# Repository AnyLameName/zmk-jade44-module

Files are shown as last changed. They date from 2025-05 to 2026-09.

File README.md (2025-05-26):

# Jade44 - A ZMK Keyboard Module

The Jade44 keyboard is a bespoke keyboard, designed for a userbase of one. 
This repository contains a module for the [ZMK Firmware](https://zmk.dev/) Project that will enable you to build
a firmware for the Jade44.

It also defines a GitHub Actions Workflow that will automatically build the firmware when a change is pushed.

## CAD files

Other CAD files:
kicad/models/EC12E2440301/ec12e2440301_3D.dxf

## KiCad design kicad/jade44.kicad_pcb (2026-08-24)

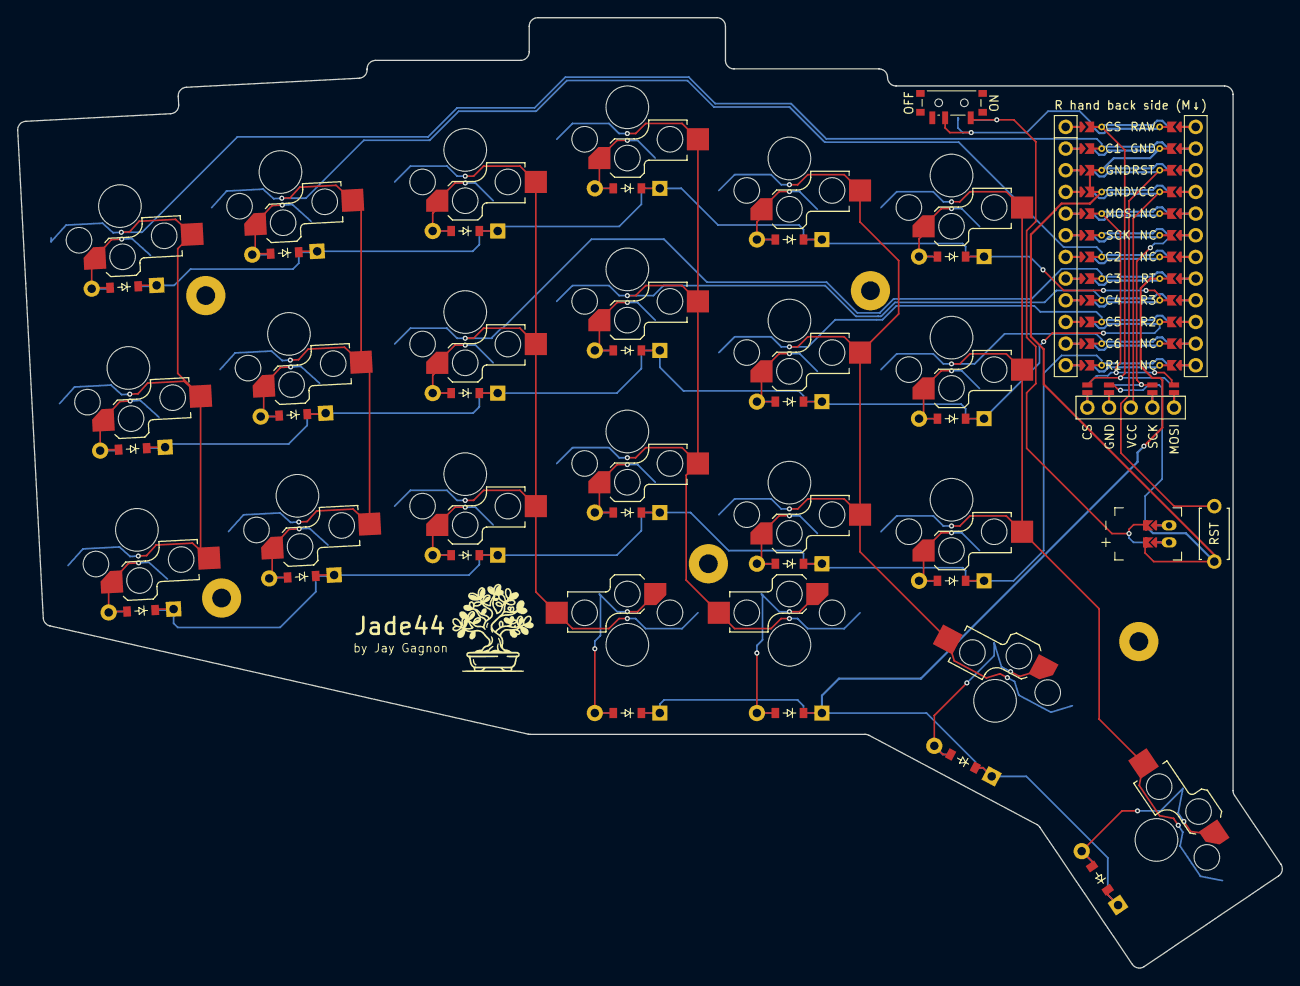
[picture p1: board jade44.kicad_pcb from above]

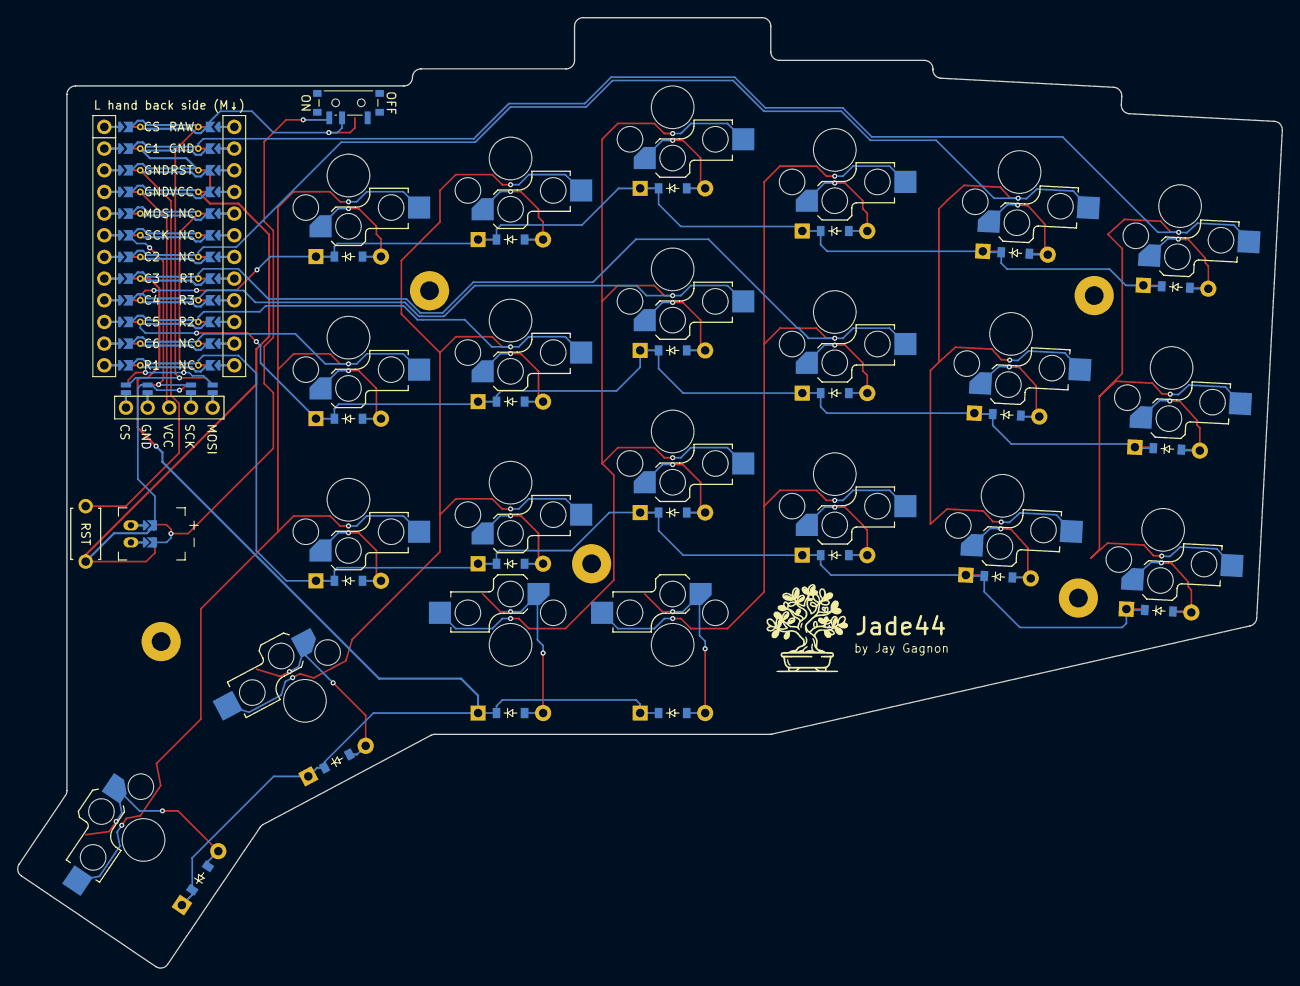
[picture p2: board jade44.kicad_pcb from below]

Board: 2 copper layers, 148.2 x 111.4 mm, 54 parts (25 on the bottom side), 47 nets.

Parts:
D1, D2, D3, D4, D5, D6, D7, D8, D9, D10, D11, D12, D13, D14, D15, D16, D17, D18, D19, D20, D21, D22: diode_tht_sod123
DISP1: display_nice_view
JST1: battery_connector_jst_ph_2
MCU1: mcu_nice_nano
MH1, MH2, MH3, MH4, MH5: mounting_hole_npth
PWR1: power_switch_smd_side
RST1: reset_switch_tht_top
S1, S2, S3, S4, S5, S6, S7, S8, S9, S10, S11, S12, S13, S14, S15, S16, S17, S18, S19, S20, S21, S22: switch_choc_v1_v2

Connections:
BAT_P: JST1.1, PWR1.1, PWR1.3
C1: MCU1.123, S1.2, S2.2, S3.2
C1_R1: D1.2, S1.1
C1_R2: D2.2, S2.1
C1_R3: D3.2, S3.1
C2: MCU1.118, S4.2, S5.2, S6.2
C2_R1: D4.2, S4.1
C2_R2: D5.2, S5.1
C2_R3: D6.2, S6.1
C3: MCU1.117, S7.2, S8.2, S9.2, S19.2
C3_R1: D7.2, S7.1
C3_R2: D8.2, S8.1
C3_R3: D9.2, S9.1
C3_RT: D19.2, S19.1
C4: MCU1.116, S10.2, S11.2, S12.2, S20.2
C4_R1: D10.2, S10.1
C4_R2: D11.2, S11.1
C4_R3: D12.2, S12.1
C4_RT: D20.2, S20.1
C5: MCU1.115, S13.2, S14.2, S15.2, S21.2
C5_R1: D13.2, S13.1
C5_R2: D14.2, S14.1
C5_R3: D15.2, S15.1
C5_RT: D21.2, S21.1
C6: MCU1.114, S16.2, S17.2, S18.2, S22.2
C6_R1: D16.2, S16.1
C6_R2: D17.2, S17.1
C6_R3: D18.2, S18.1
C6_RT: D22.2, S22.1
CS: DISP1.14, DISP1.24, MCU1.124
DISP1_1: DISP1.1, DISP1.10, DISP1.23
DISP1_2: DISP1.2, DISP1.11, DISP1.22
DISP1_4: DISP1.4, DISP1.12, DISP1.21
DISP1_5: DISP1.5, DISP1.13, DISP1.20
GND: DISP1.15, DISP1.25, JST1.2, MCU1.102, MCU1.121, MCU1.122, RST1.2
JST1_1: JST1.11, JST1.21, JST1.31
JST1_2: JST1.12, JST1.22, JST1.32
MOSI: DISP1.17, DISP1.27, MCU1.120
NC: MCU1.105, MCU1.106, MCU1.107, MCU1.111, MCU1.112
R1: D1.1, D4.1, D7.1, D10.1, D13.1, D16.1, MCU1.113
R2: D2.1, D5.1, D8.1, D11.1, D14.1, D17.1, MCU1.110
R3: D3.1, D6.1, D9.1, D12.1, D15.1, D18.1, MCU1.109
RAW: MCU1.101, PWR1.2
RST: MCU1.103, RST1.1
RT: D19.1, D20.1, D21.1, D22.1, MCU1.108
SCK: DISP1.16, DISP1.26, MCU1.119
VCC: DISP1.3, MCU1.104

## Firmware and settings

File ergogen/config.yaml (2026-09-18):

meta:
  engine: 4.1.0
units:
  kx: cx
  ky: cy
  px: kx + 2.25
  py: ky + 2
points:
  zones:
    matrix:
      key.tags:
        - keys
      anchor.shift: [100, -150]
      rotate: 3
      columns:
        C1:
        C2:
          key.stagger: 3
        C3:
          key.origin: [-200, -20]
          key.splay: -3
          key.stagger: 12
        C4:
          key.stagger: 5
        C5:
          key.stagger: -6
        C6:
          key.stagger: -2
      rows:
        R1:
        R2:
        R3:
    thumb_fan:
      key.tags:
        - thumb_keys
      anchor:
        ref: matrix_C4_R1
        shift: [1, -(ky + 7)]
      columns:
        C3:
        C4.key.shift: [1, -1]
        C5.key.shift: [2, -2]
        C6.key.shift: [3, -2.75]
      rows:
        RT:
          splay: -6
    mcu:
      anchor:
        - ref: matrix_C6_R3
          shift: [20,-8]
    display:
      anchor:
        - ref: mcu
          shift: [0,-3.5]
    battery_jack:
      anchor:
        - ref: matrix_C3_R1
          shift: [4, -18]
          rotate: 260
    power_switch:
      anchor:
        - ref: matrix_C2_R1
          shift: [11, -12]
          rotate: 90
    reset_switch:
      anchor:
        - ref: matrix_C5_R3
          shift: [0, 0.5py + 1.80]
          rotate: -13
    encoder:
      anchor:
        - ref: mcu
          shift: [0, -34]
outlines:
  _keycaps:
    - what: rectangle
      where: [keys, thumb_keys]
      size: [cx, cy]
      fillet: 1
  _keyswitch_courtyards:
    - what: rectangle
      where: [keys, thumb_keys]
      size: [15, 15]
      fillet: 0.5
  _keyswitch_cutouts:
    - what: rectangle
      where: [keys, thumb_keys]
      size: [14, 14]
      fillet: 0.5
  _power_switch:
    - what: rectangle
      where: power_switch
      size: [8.75, 2]
  _battery_jack:
    - what: rectangle
      where: battery_jack
      size: [6.5, 12]
  _reset_switch:
    - what: rectangle
      where: reset_switch
      size: [7.25, 3.25]
  _encoder:
    - what: rectangle
      where: encoder
      size: [13.2, 14]
      fillet: 1.5
    - what: circle
      where: encoder
      radius: 3
      operation: stack
    - what: circle
      where: encoder
      radius: 3.3
      operation: stack
  _encoder_pins:
    - what: rectangle
      where: encoder
      size: [7, 1.5]
      adjust:
        shift: [0, 7]
  _board:
    - what: polygon
      fillet: 1
      points: 
        # Start top left the board
        - ref: matrix_C1_R3
          shift: [-px/2, py/2]
        # Go directly to highest column  
        - ref: matrix_C4_R3
          shift: [-px/2, py/2]
        - shift: [px, 0]
        # Frame around the MCU  
        - ref: mcu
          shift: [-10, 16.85]
        - shift: [20, 0]
        # A nice vertical edge, maybe room for an encoder?
        - shift: [0, -69]
        - ref: thumb_fan_C6_RT
          shift: [px/2, py/2]
        - shift: [0, -py]
        # Fancy dance around the thumb fan  
        - aggregate:
            parts: [thumb_fan_C5_RT, thumb_fan_C6_RT]
          shift: [0, -py/2]
        - aggregate: 
            parts: [thumb_fan_C4_RT, thumb_fan_C5_RT]
          shift: [0, -py/2]
        - aggregate:
            parts: [thumb_fan_C3_RT, thumb_fan_C4_RT]
          shift: [0, -py/2]
        - ref: thumb_fan_C3_RT
          shift: [-px/2, -py/2]
        # Finish at bottom left of board, Ergogen will close the polygon off to the first point automatically.  
        - ref: matrix_C1_R1
          shift: [-px/2, -py/2]
  _mcu:
    - what: rectangle
      where: mcu
      size: [17.78,33]
      fillet: 1
    - what: rectangle
      where: mcu
      size: [8.94,7.35]
      fillet: 0.1
      operation: stack
      adjust:
        shift: [0,33/2-7.35/2+0.7]
  _mcu_socket:
    # Socket rows, only useful for the plate.
    - what: rectangle
      where: mcu
      adjust:
        shift: [(17.78 - 2.50) / 2, -2.50 / 2]
      size: [3.25, 31.25]
      operation: stack
    - what: rectangle
      where: mcu
      adjust:
        shift: [-(17.78 - 2.50) / 2, -2.50 / 2]
      size: [3.25, 31.25]
      operation: stack
  _display_socket:
    - what: rectangle
      where: display
      size: [13, 3]
      operation: stack
      fillet: 0.1
      adjust:
        shift: [0,-16.7]
  _display:
    - what: rectangle
      where: display
      size: [14,36]
      fillet: 0.5
    - what: rectangle
      where: display
      size: [10.8,24.6]
      operation: stack
      adjust:
        shift: [0,-0.75]
    - what: outline
      name: _display_socket
      operation: stack
  _mcu_cluster:
    - what: outline
      name: _mcu
      operation: stack
    - what: outline
      name: _display
      operation: stack
    - what: outline
      name: _mcu_socket
      operation: stack
  plate:
    - what: outline
      name: _board
    - what: outline
      name: _mcu_socket
      operation: stack
    - what: outline
      name: _display_socket
      operation: stack
    - what: outline
      name: _keyswitch_cutouts
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

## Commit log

2026-06-22 Pin to zmk v0.3
2026-06-25 Bind a BT Clear button.
2026-06-26 Think I had the diode direction wrong.
2026-06-26 Looks good now. Just had the diodes backwards. No need for a dedicated BT clear right now.
2026-06-26 Both halves use the same pinout right now, so column pinouts should be defined in the main devicetree file.
2026-06-27 Switch to built-in screen widget, disable WPM.
2026-08-16 Add initial configuration for ergogen.
    Technically usable, but missing screw holes and some net labeling.
    [config.yaml]
2026-08-17 Adding ceoloide footprints as a submodule.
2026-08-17 Add through-holes to the diode footprints, ignore ergogen output in repository.
2026-08-17 Make diodes reversible, move them to above switches.
2026-08-17 Move diode out of the way of the switch.
2026-08-18 Add some 3D models to help figure out how to get the diodes clear of the switches without going off the board.
2026-08-21 Label MCU pins, fix net naming for matrix keys.
    [config.yaml]
2026-08-21 Forgot to rename ref for power switch.
2026-08-21 Move power and reset switches to back, add screw holes.
2026-08-22 Add tweaked and routed pcb and symbol file for logo.
    [jade44.kicad_pcb]
2026-08-24 Add bluetooth bindings for selecting profiles 1-5 and a "clear current profile" button.
    Fixes #2
2026-08-24 Fillet pcb outline.
    [jade44.kicad_pcb]
2026-08-24 Address a pile of DRC issues.
    [jade44.kicad_pcb]
2026-08-27 Need to flip the columns on the right half with a reversible board.
2026-09-02 Post-assembly testing revealed some keymap mistakes. (#4)
2026-09-05 No usb logging (#5)
    * Post-assembly testing revealed some keymap mistakes.
    * Seems to be behaving. Time to turn off logging.
2026-09-06 Ergogen output fix (#7)
    * Watch script that will auto-generate pcb, dxf, and svg files when config.yaml is updated.
    * Adjust keycap fillet to match what I actually bought, add screwholes to outline. Should really help with case design.
    * Had Delete on the wrong layer. Very awkward chord to press.
    [config.yaml]
2026-09-07 Start on v2 PCB (#10)
    * The v2 redesign begins in earnest. Bringing in the thumb fan and completely reworking how the outline is drawn.
    * Pretty up the outline a bit.
    * Tentative positions for new screw holes. Some will almost definitely end up moving.
    Also added slightly more padding around the keys, to make sure the socket pads fit.
    * Some space/footprint optimizations:
    * Screw hole adjustments to make them a bit safer in terms of keyswitch collisions.
    * Slight increase to padding on the horizontal edges, as the switch socket pads were a bit squeezed.
    * Eliminate through-hole diode options to clean up the visuals on the front of the board as well as free up a surprising amount of spac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
    [config.yaml]
2026-09-12 Encoder support, among other things (#11)
    * Nevermind soft off, let's settle for standard idle sleep behavior, and hard power switches are more straightforward anyway.
    Fix typo.
    Trying out some power-saving functionality.
    * Slight increase to padding on t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
    [ec12e2440301_3D.dxf]
2026-09-17 Remove PCB mounting holes, as we're letting the switches connect the PCB to the plate. (#14)
2026-09-18 Rebase fixup, MCU socket plate adjustments, EC12 plate adjustments (#16)
    *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
    [config.yaml]
2026-10-27 Majority of v2 work (#18)
    There's a lot here, but the gist is:
    Add an EC12 Encoder in the empty spot between the MCU and thumb fan
    Add a bunch of step files that are now included in the pcb file automatically
    Redo thumb fan to be more compact
    Change to SMD diodes
    Replace power switch with a "reset switch" that is actually just a place to solder to jumper wires to a case-mounted switch
    Greatly enhance the plate outline so I don't have to model basically any of it
    Remove space above and to the right of the MCU so it will look nicer with a proper enclosure
    Fixes #15
2026-10-30 This should make diode routing much nicer. (#27)
2026-11-02 Reposition power switch footprint. (#28)
    Fixes #17
2026-11-03 Updating step and kicad_pcb files with *hopefully* the final v2 PCB. (#29)
